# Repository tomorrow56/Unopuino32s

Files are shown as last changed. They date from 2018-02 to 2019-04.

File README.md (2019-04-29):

# Unopuino32s ESP-WROOM-32 Breakout board with CP2102

This is the uno shaped ESP32 breakout board data.

Arduino UnoフォームのESP32ブレークアウト基板です。
- ピン配置及び取り付け穴位置がUnoと同一
- Arduino IDEからの自動書込み対応
- IO電圧: 3.3V(裏面に5V入力時の分割用の抵抗パターン有)
- 電源入力電圧範囲: 4.5V～8.0V
- USB-Serial: CP2102 (Silicon Laboratories製)
- I2C接続(4pin) 0.96インチ OLED接続用コネクタ

### Web site
 https://thousandiy.wordpress.com/2017/07/05/esp-wroom-32-breakout-board-unopuino32s-cp2102-version/

### Switch Science Web Shop
 https://www.switch-science.com/catalog/3456/

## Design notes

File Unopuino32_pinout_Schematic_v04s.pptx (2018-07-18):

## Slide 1

Unopuino32 v0.4So Pinout

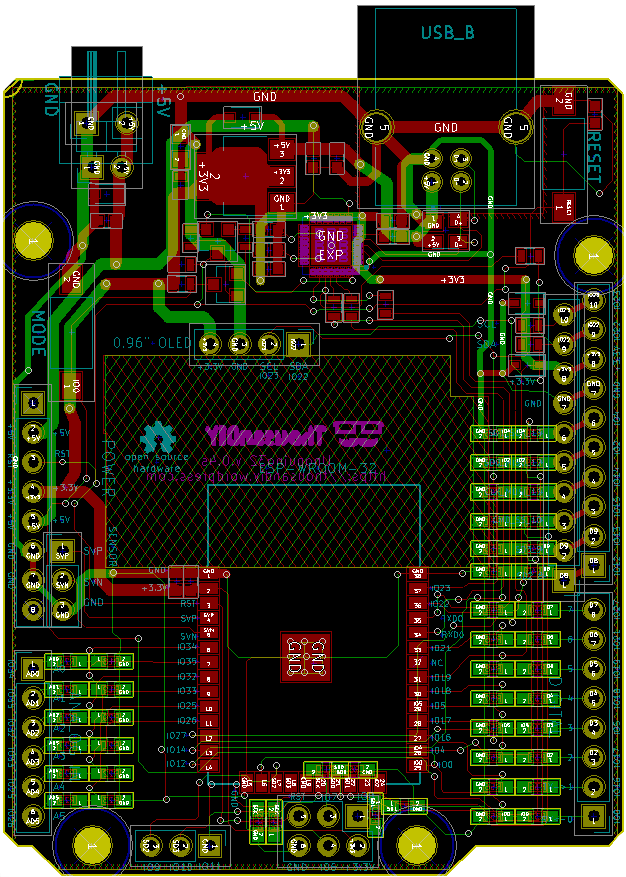
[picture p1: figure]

I2C_SCL

I2C_SDA

3.3V

GND

GPIO23

GPIO22

GPIO23

VSPI_MOSI

I2C_SCL

GND

GPIO22

3.3V

I2C_SDA

3.3V

EN

5V

GPIO4

GPIO2

GPIO14

ADC2_6

ADC2_0

ADC2_2

Touch2

Touch6

Touch0

SDIO_SD1

SDIO_SD0

SDIO_CLK

MTMS

GND

GND

5V

SensVN

SensVP

GPI36

GPI39

ADC1_0

ADC1_3

GPIO15

GPIO12

GPIO13

ADC2_3

ADC2_5

ADC2_4

Touch3

Touch4

Touch5

SDIO_CMD

SDIO_SD3

SDIO_SD2

MTDO

MTCK

MTDI

ADC1_6

GPI34

GND

GPIO27

GPIO21

GPIO19

ADC2_7

Touch7

VSPI_MISO

Touch9

ADC1_4

ADC1_7

GPO32

GPI35

D8

D9

SD0

SD1

GPIO18

GPIO5

VSPI_SCK

VSPI_SS

DAC_1

DAC_2

Touch8

ADC1_5

ADC2_8

ADC2_9

GPIO26

GPIO25

GPO33

EN

GPIO7

GPIO8

GPIO17

GPIO16

GPIO0

ADC2_1

Touch1

GPIO9

GPIO10

GPIO11

GND

GPIO6

3.3V

SD2

SD3

CMD

CLK

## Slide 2

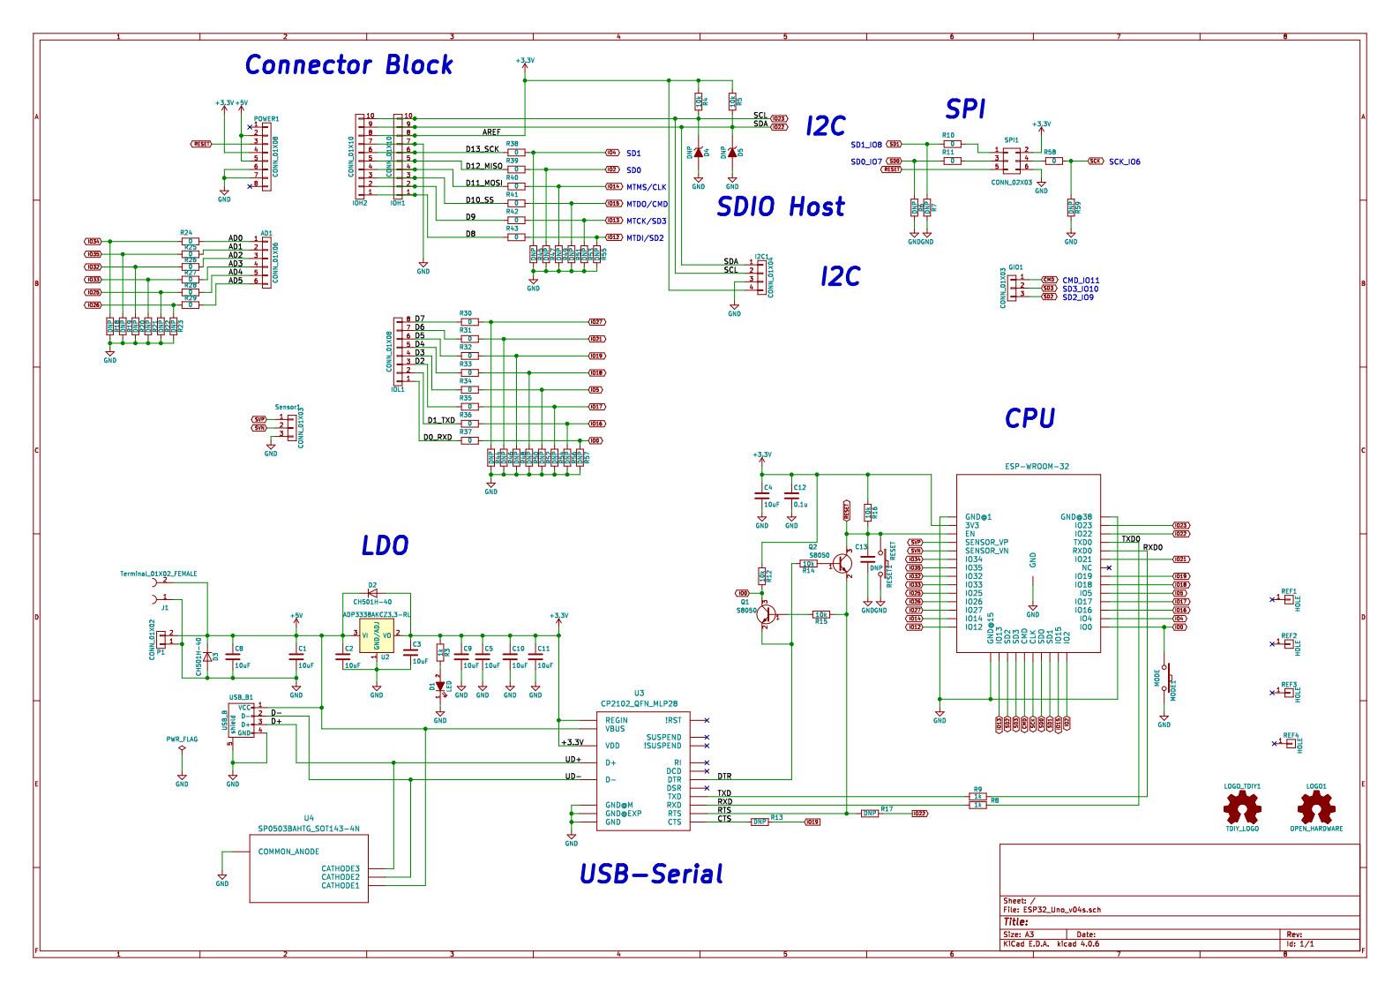
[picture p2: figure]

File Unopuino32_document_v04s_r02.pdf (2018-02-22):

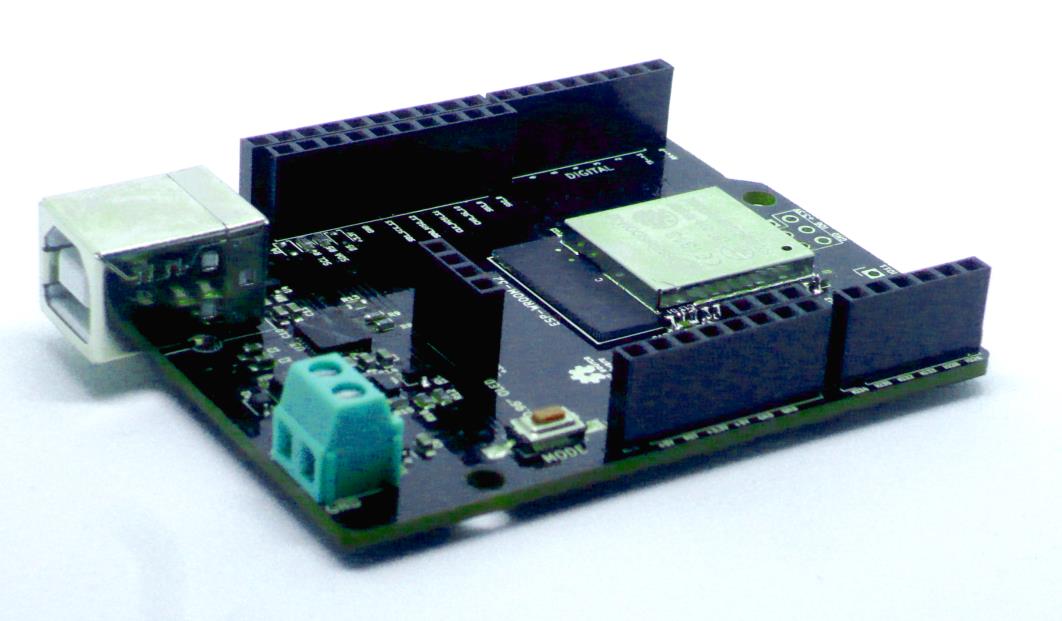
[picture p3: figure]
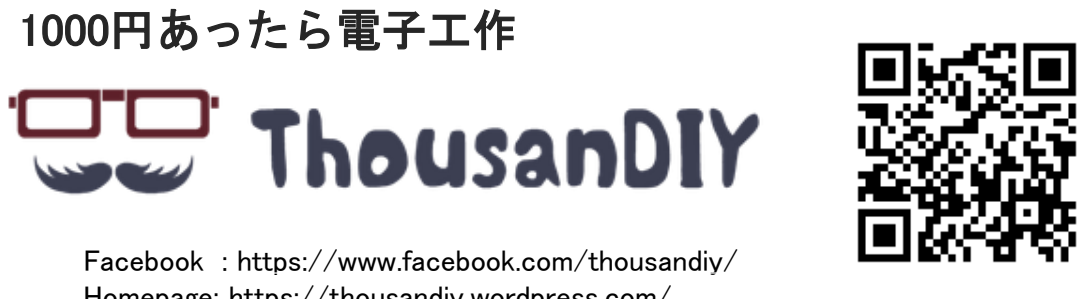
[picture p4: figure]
1000円あったら電子工作

Facebook : https://www.facebook.com/thousandiy/Homepage: https://thousandiy.wordpress.com/

# ESP-WROOM-32 Breakout board （CP2102 version)

## Arduino UnoフォームのESP32ブレークアウト基板です。

- ピン配置及び取り付け穴位置がUnoと同一※1
- Arduino IDEからの自動書込み対応
- IO電圧: 3.3V(裏面に5V入力時の分割用の抵抗パターン有)
- 電源入力電圧範囲: 4.5V～8.0V
- USB-Serial: CP2102 (Silicon Laboratories製)
- I2C接続(4pin) 0.96インチ OLED接続用コネクタ※2

※1 ESP32はArduino IDEで開発できますが、ライブラリレベルでの互換はありません ※2 OLEDは電源/GNDの配置が違うものがあるので購入の際は確認してください

## インストール方法や各種情報は以下で公開しています

## https://goo.gl/3g5hZB

## Schematic

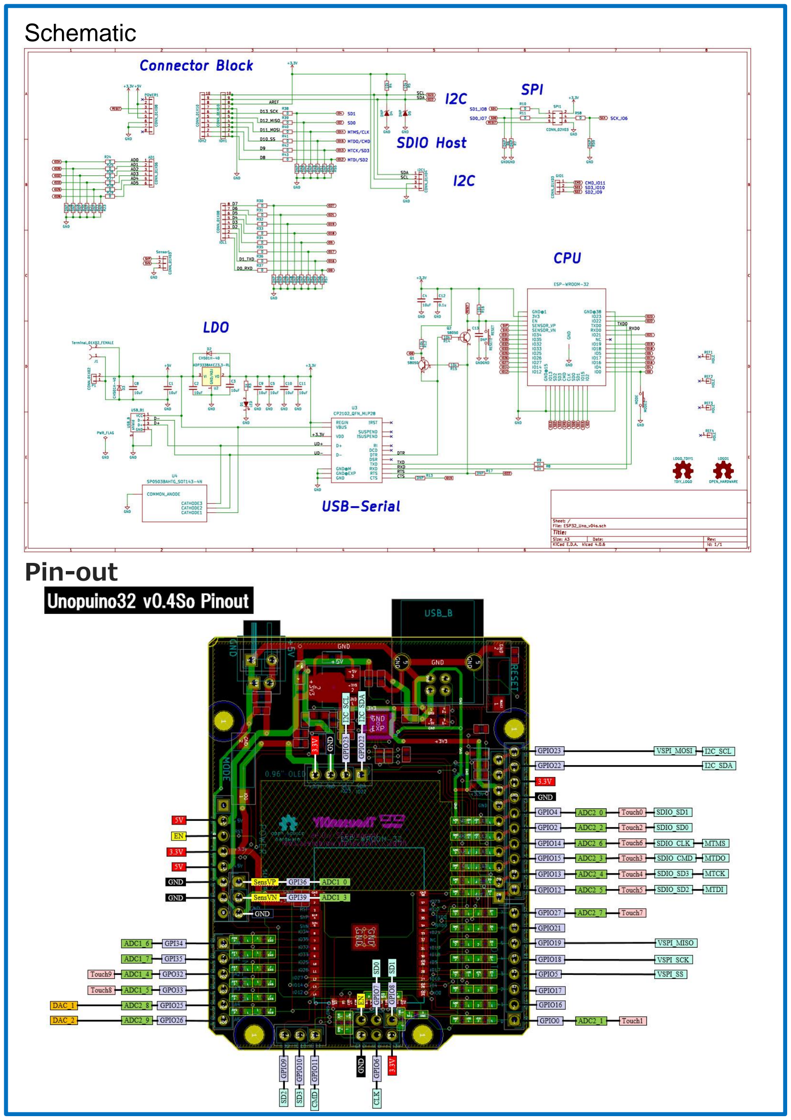
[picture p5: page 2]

## Pin-out

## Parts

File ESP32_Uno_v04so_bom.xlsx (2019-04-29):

Reference | Value | Footprint | side
C1 | 10uF | Capacitors_SMD:C_0603
C2 | 10uF | Capacitors_SMD:C_0603
C3 | 10uF | Capacitors_SMD:C_0603
C4 | 10uF | Capacitors_SMD:C_0603
C5 | 10uF | Capacitors_SMD:C_0603
C8 | 10uF | Capacitors_SMD:C_0603
C9 | 10uF | Capacitors_SMD:C_0603
C10 | 10uF | Capacitors_SMD:C_0603
C11 | 10uF | Capacitors_SMD:C_0603
C12 | 0.1u | Capacitors_SMD:C_0603
C13 | DNP | Capacitors_SMD:C_0603 | DNP
D1 | LED | LEDs:LED_0805
D2 | CH501H-40 | Diodes_SMD:D_SOD-323
D3 | CH501H-40 | Diodes_SMD:D_SOD-323
D4 | DNP | Diodes_SMD:D_SOD-323 | DNP
D5 | DNP | Diodes_SMD:D_SOD-323 | DNP
Q1 | S8050 | TO_SOT_Packages_SMD:SOT-23
Q2 | S8050 | TO_SOT_Packages_SMD:SOT-23
R3 | 1k | Resistors_SMD:R_0603
R4 | 10k | Resistors_SMD:R_0603
R5 | 10k | Resistors_SMD:R_0603
R6 | DNP | Resistors_SMD:R_0603_HandSoldering | DNP
R7 | DNP | Resistors_SMD:R_0603_HandSoldering | DNP
R8 | 1k | Resistors_SMD:R_0603
R9 | 1k | Resistors_SMD:R_0603
R10 | 0 | Resistors_SMD:R_0603_HandSoldering | DNP
R11 | 0 | Resistors_SMD:R_0603_HandSoldering | DNP
R12 | 10k | Resistors_SMD:R_0603
R13 | DNP | Resistors_SMD:R_0603 | DNP
R14 | 10k | Resistors_SMD:R_0603
R15 | 10k | Resistors_SMD:R_0603
R16 | 10k | Resistors_SMD:R_0603
R17 | DNP | Resistors_SMD:R_0603 | DNP
R18 | DNP | Resistors_SMD:R_0603_HandSoldering | DNP
R19 | DNP | Resistors_SMD:R_0603_HandSoldering | DNP
R20 | DNP | Resistors_SMD:R_0603_HandSoldering | DNP
R21 | DNP | Resistors_SMD:R_0603_HandSoldering | DNP
R22 | DNP | Resistors_SMD:R_0603_HandSoldering | DNP
R23 | DNP | Resistors_SMD:R_0603_HandSoldering | DNP
R24 | 0 | Resistors_SMD:R_0603_HandSoldering
R25 | 0 | Resistors_SMD:R_0603_HandSoldering
R26 | 0 | Resistors_SMD:R_0603_HandSoldering
R27 | 0 | Resistors_SMD:R_0603_HandSoldering
R28 | 0 | Resistors_SMD:R_0603_HandSoldering
R29 | 0 | Resistors_SMD:R_0603_HandSoldering
R30 | 0 | Resistors_SMD:R_0603_HandSoldering
R31 | 0 | Resistors_SMD:R_0603_HandSoldering
R32 | 0 | Resistors_SMD:R_0603_HandSoldering
R33 | 0 | Resistors_SMD:R_0603_HandSoldering
R34 | 0 | Resistors_SMD:R_0603_HandSoldering
R35 | 0 | Resistors_SMD:R_0603_HandSoldering
R36 | 0 | Resistors_SMD:R_0603_HandSoldering
R37 | 0 | Resistors_SMD:R_0603_HandSoldering
R38 | 0 | Resistors_SMD:R_0603_HandSoldering
R39 | 0 | Resistors_SMD:R_0603_HandSoldering
R40 | 0 | Resistors_SMD:R_0603_HandSoldering
R41 | 0 | Resistors_SMD:R_0603_HandSoldering
R42 | 0 | Resistors_SMD:R_0603_HandSoldering
R43 | 0 | Resistors_SMD:R_0603_HandSoldering
R44 | DNP | Resistors_SMD:R_0603_HandSoldering | DNP
R45 | DNP | Resistors_SMD:R_0603_HandSoldering | DNP
R46 | DNP | Resistors_SMD:R_0603_HandSoldering | DNP
R47 | DNP | Resistors_SMD:R_0603_HandSoldering | DNP
R48 | DNP | Resistors_SMD:R_0603_HandSoldering | DNP
R49 | DNP | Resistors_SMD:R_0603_HandSoldering | DNP
R50 | DNP | Resistors_SMD:R_0603_HandSoldering | DNP
R51 | DNP | Resistors_SMD:R_0603_HandSoldering | DNP
R52 | DNP | Resistors_SMD:R_0603_HandSoldering | DNP
R53 | DNP | Resistors_SMD:R_0603_HandSoldering | DNP
R54 | DNP | Resistors_SMD:R_0603_HandSoldering | DNP
R55 | DNP | Resistors_SMD:R_0603_HandSoldering | DNP
R56 | DNP | Resistors_SMD:R_0603_HandSoldering | DNP
R57 | DNP | Resistors_SMD:R_0603_HandSoldering | DNP
R58 | 0 | Resistors_SMD:R_0603_HandSoldering | DNP
R59 | DNP | Resistors_SMD:R_0603_HandSoldering | DNP
MODE1 | MODE | Buttons_Switches_SMD:SW_SPST_FSMSM
RESET1 | RESET | Buttons_Switches_SMD:SW_SPST_FSMSM
U1 | ESP-WROOM-32 | footprint:ESP-WROOM-32_aki
U2 | ADP3338AKCZ3.3-RL | TO_SOT_Packages_SMD:SOT-223-3Lead_TabPin2
U3 | CP2102_QFN_MLP28 | footprint:CP2102_MLP28
U4 | SP0503BAHTG_SOT143-4N | TO_SOT_Packages_SMD:SOT-143
AD1 | CONN_01X06 | Pin_Headers:Pin_Header_Straight_1x06_Pitch2.54mm
GIO1 | CONN_01X03 | Pin_Headers:Pin_Header_Straight_1x03_Pitch2.54mm | DNP
I2C1 | CONN_01X04 | Pin_Headers:Pin_Header_Straight_1x04_Pitch2.54mm
IOH1 | CONN_01X10 | Pin_Headers:Pin_Header_Straight_1x10_Pitch2.54mm
IOH2 | CONN_01X10 | Pin_Headers:Pin_Header_Straight_1x10_Pitch2.54mm
IOL1 | CONN_01X08 | Pin_Headers:Pin_Header_Straight_1x08_Pitch2.54mm
Sensor1 | CONN_01X03 | Pin_Headers:Pin_Header_Straight_1x03_Pitch2.54mm
SPI1 | CONN_02X03 | Pin_Headers:Pin_Header_Straight_2x03_Pitch2.54mm | DNP
P1 | CONN_01X02 | Pin_Headers:Pin_Header_Angled_1x02_Pitch2.54mm
POWER1 | CONN_01X08 | Pin_Headers:Pin_Header_Straight_1x08_Pitch2.54mm
J1 | Terminal_01X02_FEMALE | footprint:Terminal_2pin_Pitch3.5mm
USB_B1 | USB_B | Connect:USB_B
REF1 | HOLE | Mounting_Holes:MountingHole_3.2mm_M3
REF2 | HOLE | Mounting_Holes:MountingHole_3.2mm_M3
REF3 | HOLE | Mounting_Holes:MountingHole_3.2mm_M3
REF4 | HOLE | Mounting_Holes:MountingHole_3.2mm_M3
LOGO_TDIY1 | TDIY_LOGO | footprint:TDIY-LOGO-S
LOGO1 | OPEN_HARDWARE | footprint:OSHW-logo_silkscreen-front_3mm

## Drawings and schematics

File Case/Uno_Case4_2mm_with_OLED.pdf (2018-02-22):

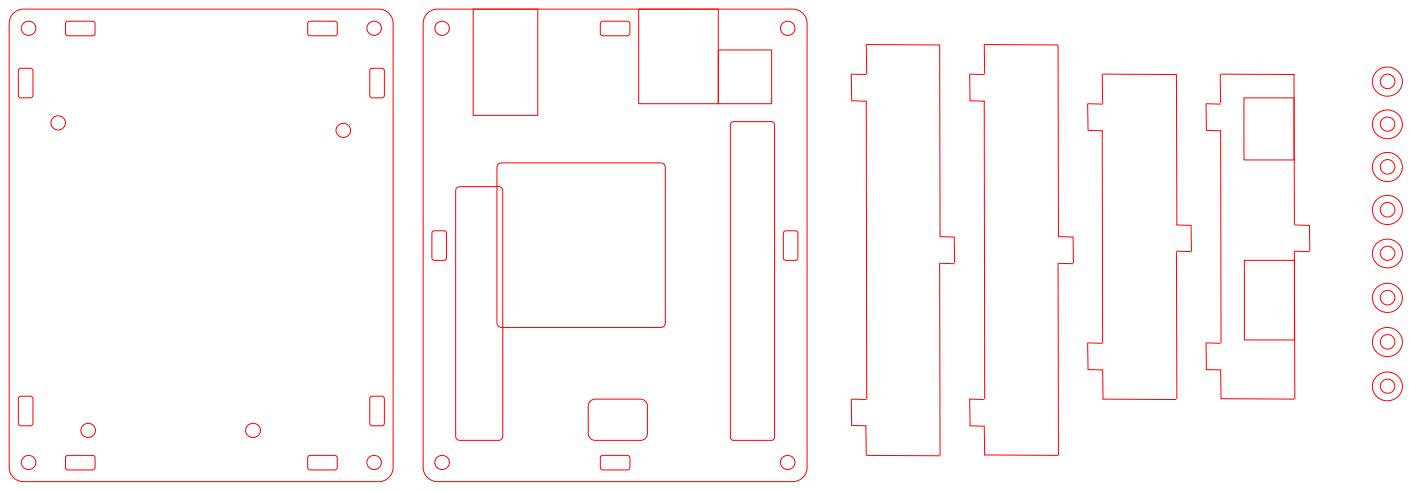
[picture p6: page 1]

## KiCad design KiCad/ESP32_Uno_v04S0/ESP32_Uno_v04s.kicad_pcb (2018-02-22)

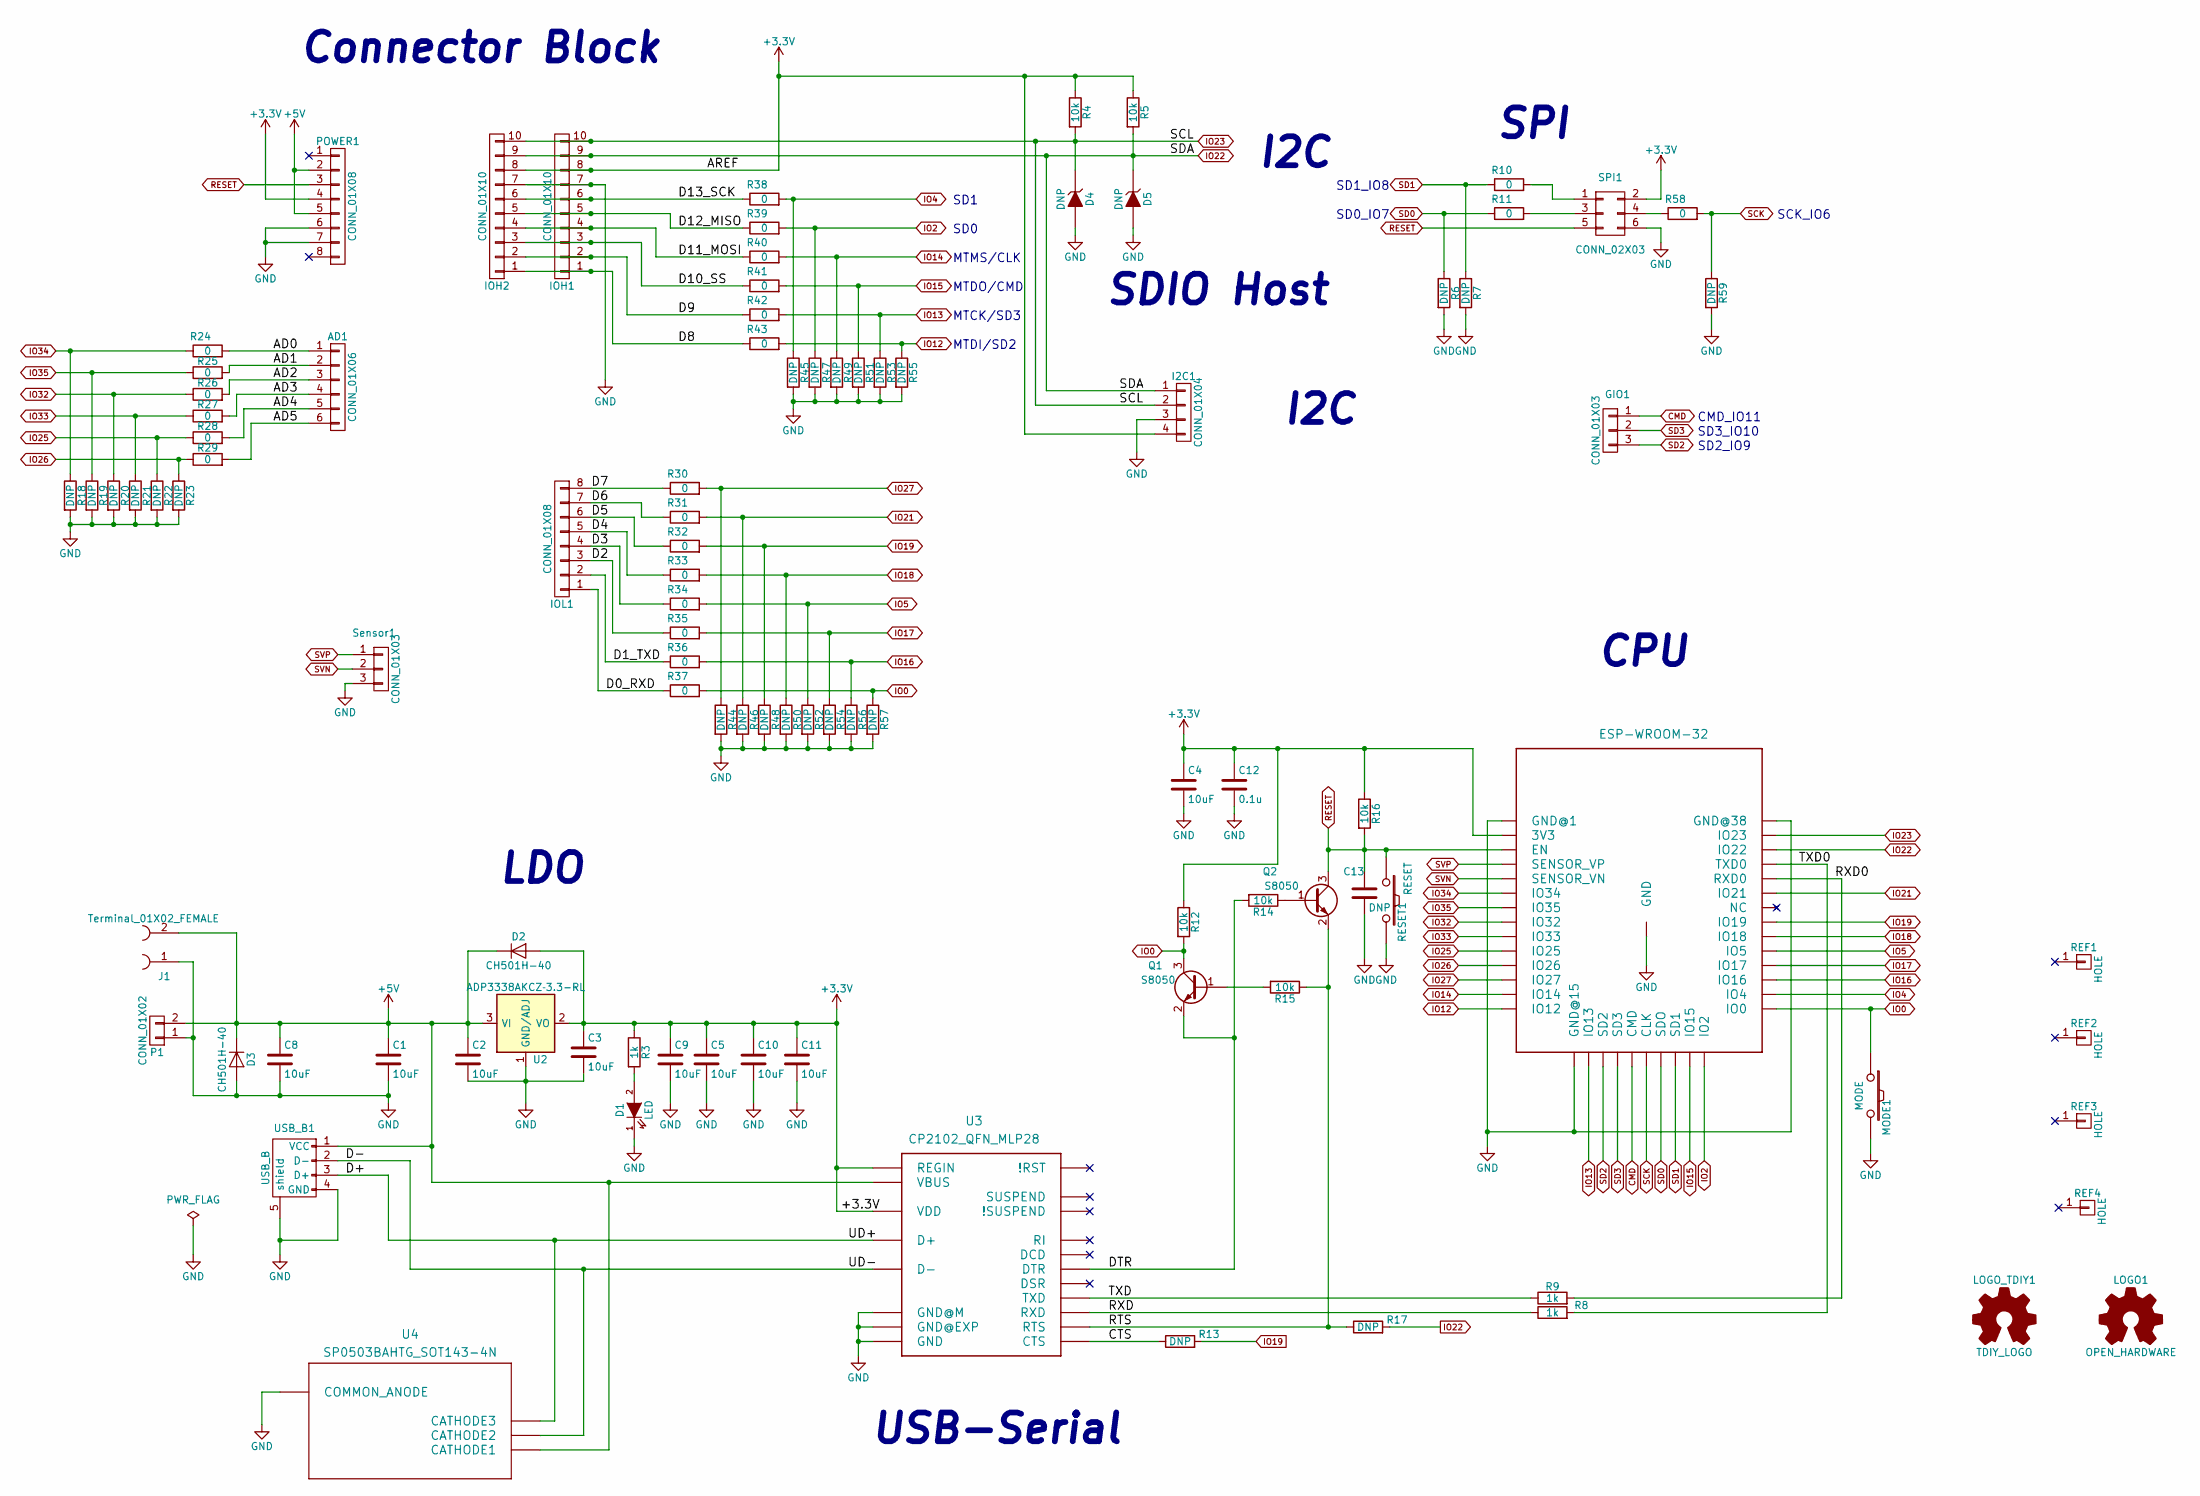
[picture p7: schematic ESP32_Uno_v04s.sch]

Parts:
AD1: CONN_01X06; Pin_Header_Straight_1x06_Pitch2.54mm
C1, C2, C3, C4, C5, C8, C9, C10, C11: 10uF; C_0603
C12: 0.1u; C_0603
C13: DNP; C_0603
D1: LED; LED_0805
D2, D3: CH501H-40; D_SOD-323
D4, D5: DNP; D_SOD-323
GIO1: CONN_01X03; Pin_Header_Straight_1x03_Pitch2.54mm
I2C1: CONN_01X04; Pin_Header_Straight_1x04_Pitch2.54mm
IOH1, IOH2: CONN_01X10; Pin_Header_Straight_1x10_Pitch2.54mm
IOL1: CONN_01X08; Pin_Header_Straight_1x08_Pitch2.54mm
J1: Terminal_01X02_FEMALE; Terminal_2pin_Pitch3.5mm
LOGO1: OPEN_HARDWARE; OSHW-logo_silkscreen-front_3mm
LOGO_TDIY1: TDIY_LOGO; TDIY-LOGO-S
MODE1: MODE; SW_SPST_FSMSM
P1: CONN_01X02; Pin_Header_Angled_1x02_Pitch2.54mm
POWER1: CONN_01X08; Pin_Header_Straight_1x08_Pitch2.54mm
Q1, Q2: S8050; SOT-23
R3, R8, R9: 1k; R_0603
R4, R5, R12, R14, R15, R16: 10k; R_0603
R6, R7, R18, R19, R20, R21, R22, R23, R44, R45, R46, R47, R48, R49, R50, R51, R52, R53, R54, R55, R56, R57, R59: DNP; R_0603_HandSoldering
R10, R11, R24, R25, R26, R27, R28, R29, R30, R31, R32, R33, R34, R35, R36, R37, R38, R39, R40, R41, R42, R43, R58: 0; R_0603_HandSoldering
R13, R17: DNP; R_0603
REF1, REF2, REF3, REF4: HOLE; MountingHole_3.2mm_M3
RESET1: RESET; SW_SPST_FSMSM
SPI1: CONN_02X03; Pin_Header_Straight_2x03_Pitch2.54mm
Sensor1: CONN_01X03; Pin_Header_Straight_1x03_Pitch2.54mm
U1: ESP-WROOM-32; ESP-WROOM-32_aki
U2: ADP3338AKCZ­3.3-RL; SOT-223-3Lead_TabPin2
U3: CP2102_QFN_MLP28; CP2102_MLP28
U4: SP0503BAHTG_SOT143-4N; SOT-143
USB_B1: USB_B

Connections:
+3V3: C3.1, C4.1, C5.1, C9.1, C10.1, C11.1, C12.1, D2.2 (A), I2C1.4, IOH1.8, IOH2.8, POWER1.4, R3.1, R4.1, R5.1, R12.1, R16.1, SPI1.2, U1.2 (3V3), U2.2 (VO), U3.6 (VDD), U3.7 (REGIN)
+5V: C1.1, C2.1, C8.1, D2.1 (K), D3.1 (K), J1.2, P1.2, POWER1.2, POWER1.5, U2.3 (VI), U3.8 (VBUS), U4.2 (CATHODE1), USB_B1.1 (VCC)
/AD0: AD1.1, R24.2
/AD1: AD1.2, R25.2
/AD2: AD1.3, R26.2
/AD3: AD1.4, R27.2
/AD4: AD1.5, R28.2
/AD5: AD1.6, R29.2
/CTS: R13.1, U3.23 (CTS)
/D0_RXD: IOL1.1, R37.1
/D1_TXD: IOL1.2, R36.1
/D2: IOL1.3, R35.1
/D3: IOL1.4, R34.1
/D4: IOL1.5, R33.1
/D5: IOL1.6, R32.1
/D6: IOL1.7, R31.1
/D7: IOL1.8, R30.1
/D8: IOH1.1, IOH2.1, R43.1
/D9: IOH1.2, IOH2.2, R42.1
/D10_SS: IOH1.3, IOH2.3, R41.1
/D11_MOSI: IOH1.4, IOH2.4, R40.1
/D12_MISO: IOH1.5, IOH2.5, R39.1
/D13_SCK: IOH1.6, IOH2.6, R38.1
/D+: U3.4 (D+), U4.4 (CATHODE3), USB_B1.3 (D+)
/D-: U3.5 (D-), U4.3 (CATHODE2), USB_B1.2 (D-)
/DTR: Q1.2 (E), R14.2, U3.28 (DTR)
/RTS: Q2.2 (E), R15.1, R17.1, U3.24 (RTS)
/RXD: R8.1, U3.25 (RXD)
/RXD0: R9.2, U1.34 (RXD0)
/TXD: R9.1, U3.26 (TXD)
/TXD0: R8.2, U1.35 (TXD0)
CMD: GIO1.1, U1.19 (CMD)
GND: C1.2, C2.2, C3.2, C4.2, C5.2, C8.2, C9.2, C10.2, C11.2, C12.2, C13.2, D1.1 (K), D3.2 (A), D4.2 (A), D5.2 (A), I2C1.3, IOH1.7, IOH2.7, J1.1, MODE1.2, P1.1, POWER1.6, POWER1.7, R6.2, R7.2, R18.2, R19.2, R20.2, R21.2, R22.2, R23.2, R44.2, R45.2, R46.2, R47.2, R48.2, R49.2, R50.2, R51.2, R52.2, R53.2, R54.2, R55.2, R56.2, R57.2, R59.2, RESET1.2, SPI1.6, Sensor1.3, U1.1 (GND@1), U1.15 (GND@15), U1.38 (GND@38), U1.GND, U2.1 (GND/ADJ), U3.3 (GND), U3.EXP (GND@EXP), U3.M (GND@M), U4.1 (COMMON_ANODE), USB_B1.4 (GND), USB_B1.5 (shield)
IO0: MODE1.1, Q1.3 (C), R12.2, R37.2, R57.1, U1.25 (IO0)
IO2: R39.2, R47.1, U1.24 (IO2)
IO4: R38.2, R45.1, U1.26 (IO4)
IO5: R34.2, R52.1, U1.29 (IO5)
IO12: R43.2, R55.1, U1.14 (IO12)
IO13: R42.2, R53.1, U1.16 (IO13)
IO14: R40.2, R49.1, U1.13 (IO14)
IO15: R41.2, R51.1, U1.23 (IO15)
IO16: R36.2, R56.1, U1.27 (IO16)
IO17: R35.2, R54.1, U1.28 (IO17)
IO18: R33.2, R50.1, U1.30 (IO18)
IO19: R13.2, R32.2, R48.1, U1.31 (IO19)
IO21: R31.2, R46.1, U1.33 (IO21)
IO22: D5.1 (K), I2C1.1, IOH1.9, IOH2.9, R5.2, R17.2, U1.36 (IO22)
IO23: D4.1 (K), I2C1.2, IOH1.10, IOH2.10, R4.2, U1.37 (IO23)
IO25: R22.1, R28.1, U1.10 (IO25)
IO26: R23.1, R29.1, U1.11 (IO26)
IO27: R30.2, R44.1, U1.12 (IO27)
IO32: R20.1, R26.1, U1.8 (IO32)
IO33: R21.1, R27.1, U1.9 (IO33)
IO34: R18.1, R24.1, U1.6 (IO34)
IO35: R19.1, R25.1, U1.7 (IO35)
unnamed: D1.2 (A), R3.2
unnamed: Q1.1 (B), R15.2
unnamed: Q2.1 (B), R14.1
unnamed: R10.2, SPI1.1
unnamed: R11.2, SPI1.3
unnamed: R58.1, SPI1.4
RESET: C13.1, POWER1.3, Q2.3 (C), R16.2, RESET1.1, SPI1.5, U1.3 (EN)
SCK: R58.2, R59.1, U1.20 (CLK)
SD0: R6.1, R11.1, U1.21 (SDO)
SD1: R7.1, R10.1, U1.22 (SD1)
SD2: GIO1.3, U1.17 (SD2)
SD3: GIO1.2, U1.18 (SD3)
SVN: Sensor1.2, U1.5 (SENSOR_VN)
SVP: Sensor1.1, U1.4 (SENSOR_VP)

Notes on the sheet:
Connector Block
LDO
USB-Serial
CPU
SPI
SDIO Host
MTDI/SD2
MTCK/SD3
MTDO/CMD
MTMS/CLK
SD0
SD1
SD0_IO7
SD1_IO8
SD2_IO9
SD3_IO10
CMD_IO11
SCK_IO6
I2C

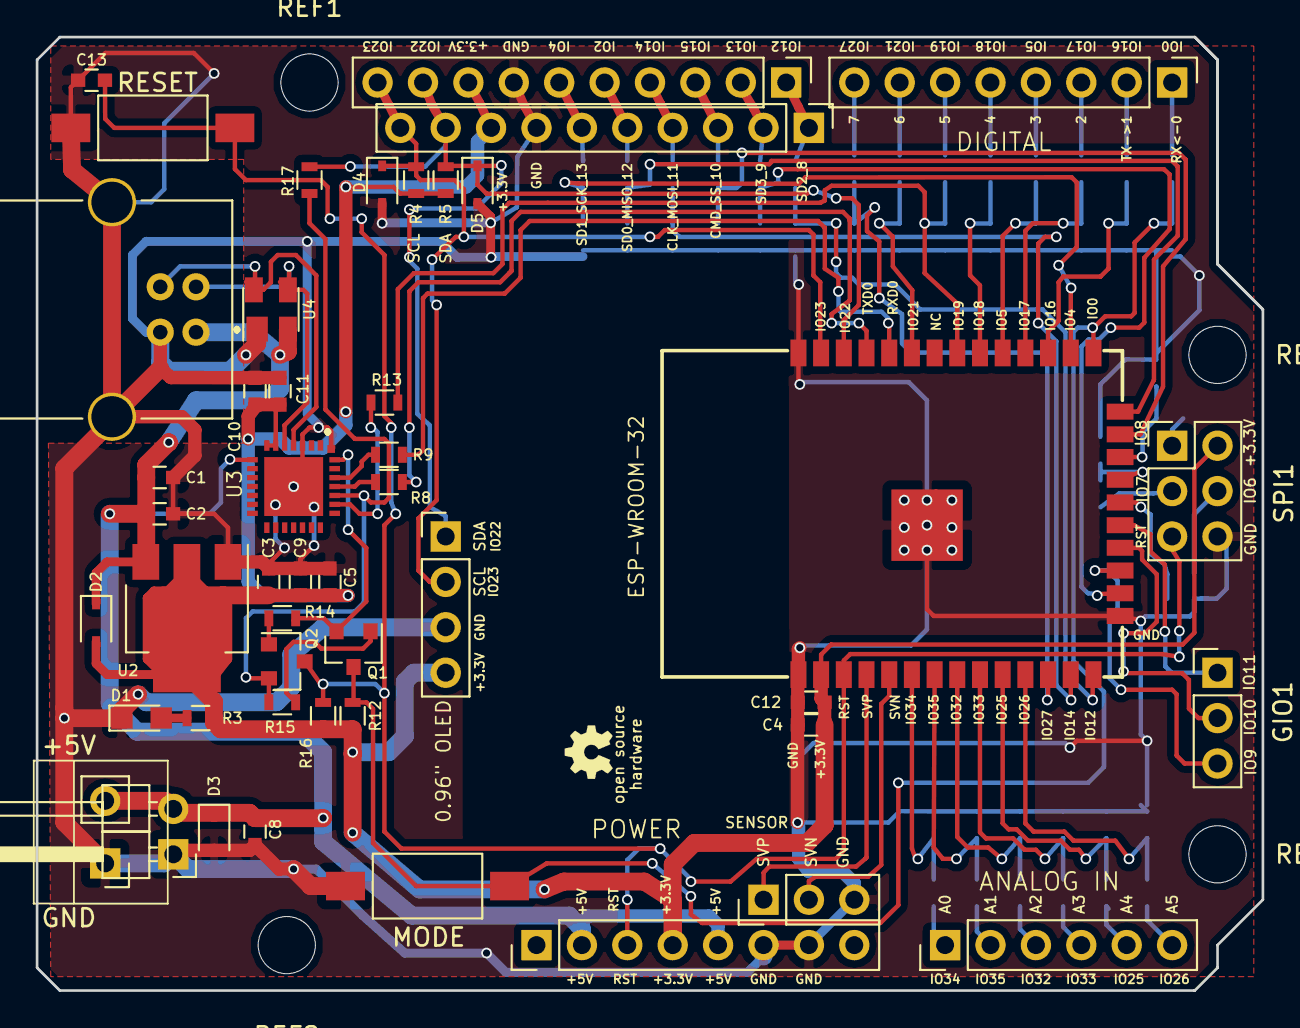
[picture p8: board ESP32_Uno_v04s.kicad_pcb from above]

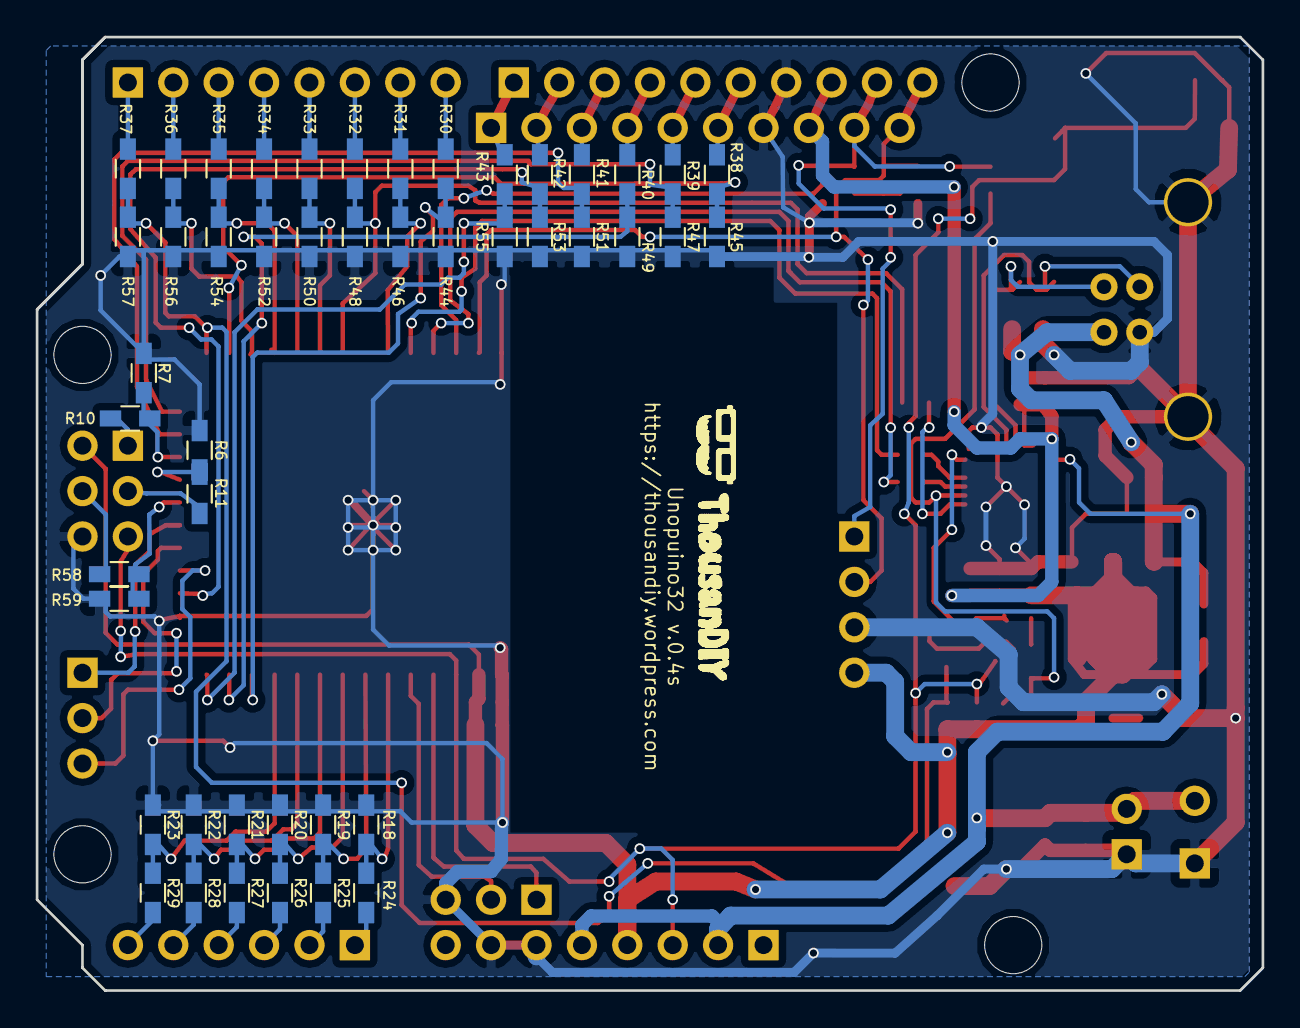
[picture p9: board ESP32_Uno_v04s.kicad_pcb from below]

Board: 2 copper layers, 68.6 x 53.3 mm, 99 parts (47 on the bottom side), 69 nets.

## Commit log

2018-02-22 Switch Science version
    [ESP32_Uno_v04s.kicad_pcb, ESP32_Uno_v04s.sch]
2018-02-23 change to use original component
    [ESP32_Uno_v04s.sch]
2018-07-18 Add pin_Label
    [UnopuinoV04_pin_rabel.xlsx]
2019-04-29 Organize the repository
    [ESP32_Uno_v04s.kicad_pcb, ESP32_Uno_v04s.sch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]
